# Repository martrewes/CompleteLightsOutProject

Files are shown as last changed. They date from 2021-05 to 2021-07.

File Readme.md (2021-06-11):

# Lights Out Physical project

- [Lights Out Physical project](#lights-out-physical-project)
  - [Intro](#intro)
  - [Edit 1](#edit-1)
    - [Items purchased so far:](#items-purchased-so-far)
    - [Dimensions of Items in mm](#dimensions-of-items-in-mm)
    - [Software](#software)
    - [Design](#design)
  - [Edit 2](#edit-2)
    - [PCB](#pcb)
  - [Edit 3](#edit-3)
  - [Edit 4](#edit-4)
    - [Button Layout](#button-layout)
    - [Serial Output](#serial-output)
  - [Edit 5](#edit-5)
    - [Playing with Sound](#playing-with-sound)
    - [**I made a grave mistake!!**](#i-made-a-grave-mistake)
  - [Edit 6](#edit-6)
    - [PCBs Arrived](#pcbs-arrived)
    - [It Verks!](#it-verks)
    - [More software work](#more-software-work)
  - [Edit 7](#edit-7)
    - [I haven't done much](#i-havent-done-much)
    - [Schematic/PCB Now Fixed](#schematicpcb-now-fixed)
- [Changes](#changes)

## Intro

After I had completed creating LightsOut in Python, I was going to make it again with a GUI. I started this process but it sort of fizzled out (though I am sure I will go back to it).

I decided in my _great wisdom_ to make a complete recreation of the game physically. The reasons for this are many, but overall I would like to achieve the following:

- Roughly design it
  - Have it use Batteries
  - Be able to charge it
  - Possibly have an additional display
  - Add sound?
- Create the circuit
- Create the PCB (and have it manufactured)
- Write the software (ESP32)
- Creating a housing (maybe send off for 3D printing)

It's quite a lofty ambition, maybe not if you're experienced which I certainly am not, but I do hope to achieve it.

## Edit 1

### Items purchased so far:

This table will be updated as and when

| Qty. | Item | Price | Arrived |
| ---- | --- | --- | --- |
| 60 | SK6812 5050 RGB LEDs | £5.00 | Yes |
| 30 | Gateron Switches Green (SMD Variant) | £9.45 | Yes |
| 1 | 15m Cat5e Cable (solid core) | £8.99 | No |
| 4 | Various pin connectors | £6.15 | No |
| 12 | 18650 Battery Holder | £6.99 | Yes |
| 5 | 1A/5V MicroUSB Li-Ion Battery Module | £6.99 | Yes |
| 1 | 60/40 Solder 100g | £6.37 | Yes |
| 1 | 1L Isopropanol 99.9% | £9.49 | Yes |
| 50 | 0.1uF 1206 SMD Capacitors | £2.30 | No |
| | **Total** | **£61.73** | |

### Dimensions of Items in mm

| Item Name | Length | Width | Height |
| --- | --- | ----- | --- |
| SK6812 5050 RGB LEDs | 5 | 5 | 1.6 |
| Gateron Switches Green (SMD Variant) | 15.8 | 15.6  | 18 |
| 18650 Battery Holder | 75.9 | 20.9  | 18.5 |
| 1A/5V MicroUSB Li-Ion Battery Module | 28.7 | 17.3  | 3.5 |
| PCB | TBD | TBD | 1.6 |
| Capacitors | 3.2 | 1.6 | 1 |

### Software

So I am starting to play around with the circuit idea. As I have never used addressable RGB led's before, I thought best to use an online simulator whilst I was waiting for them to arrive. (I will be using an ESP32 based board, however as I am just experimenting I am using an UNO online)
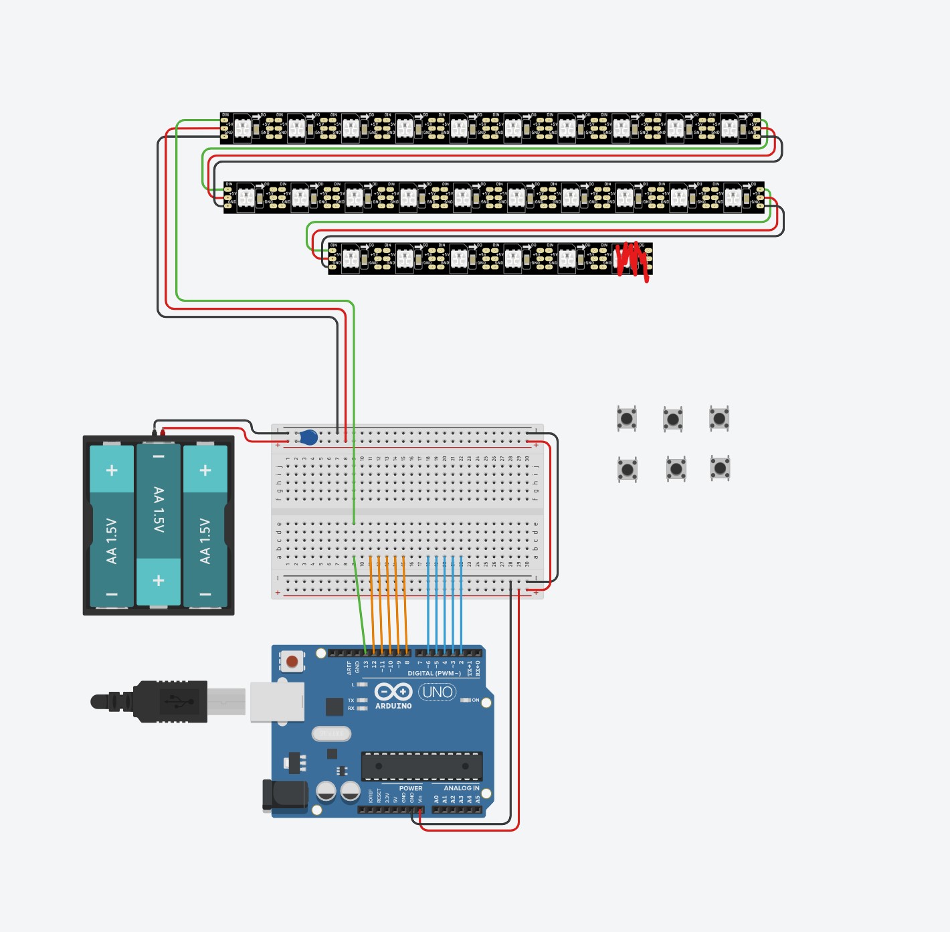
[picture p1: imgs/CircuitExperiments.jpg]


I have also done some rudimentary code along side this in the simulator to get a feel for how it works. So far I am just reading the colour of the LED, reporting it, and then changing it to another colour, rinse and repeat. I only plan to use green and red for this project.

```c++
#include <Adafruit_NeoPixel.h>

#define PIN		13
#define N_LEDS	25

Adafruit_NeoPixel strip = Adafruit_NeoPixel(N_LEDS, PIN, NEO_GRB + NEO_KHZ800);
//int req = 0;
//String hexer = "";
uint32_t red = strip.Color(255, 0, 0);
uint32_t green = strip.Color(0, 255, 0);
uint32_t active = green;
void setup()
{
  strip.begin();
  strip.show();
  Serial.begin(9600);
}

void loop()
{
  //(strip.Color(255, 0, 0)); // Red
  //(strip.Color(0, 255, 0)); // Green
  //(strip.Color(0, 0, 255)); // Blue
  strip.setPixelColor(2, active);
  strip.show();
  delay(1000);
  if (strip.getPixelColor(2) == green) {
    Serial.println("It's Green!");
    active = red;
  	strip.show();
  	}
  else {
    Serial.println("it's Red!");
    active = green;
  	strip.show();
	}

```

Next, in terms of software, I am going to work on the switch matrix and see how I can use them as a matrix.

### Design

I have also done a rough draft of what I think it will look like (completely not final). Obviously, there is a lot I need to change, but this was just to have an idea of where I am heading.
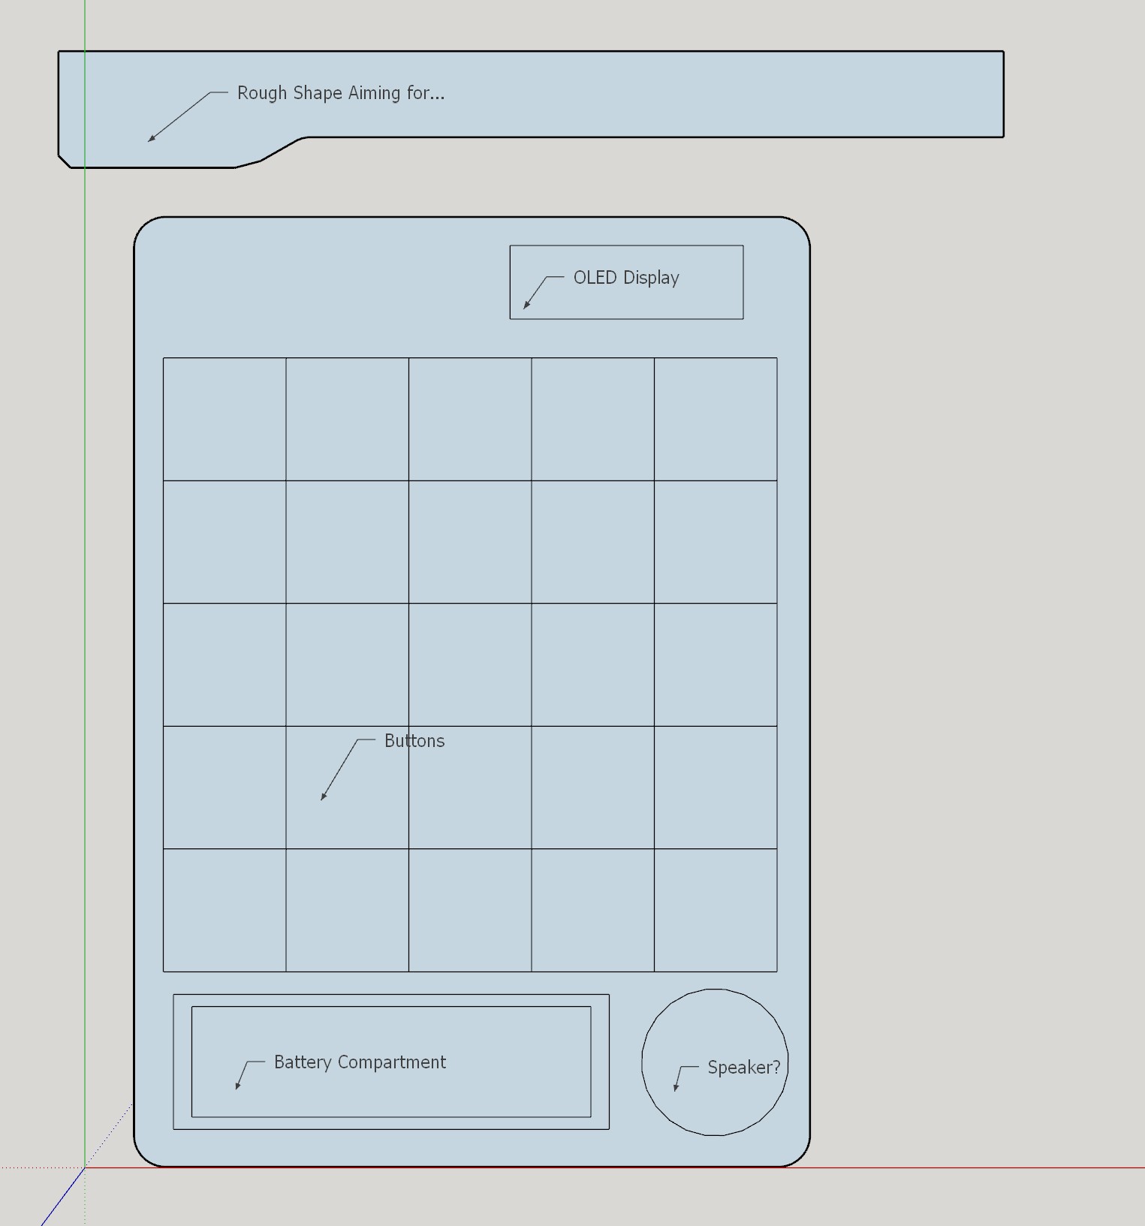
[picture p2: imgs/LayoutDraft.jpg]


## Edit 2

So I have been working on this a lot behind the scenes, but there has nothing of note really been done so far. Just a load of idea's on how to approach this. Thankfully some of the parts arrived today, so I have been able to measure and imagine how large the pcb needs to be etc. On top of that, I have also been working on a few PCB ideas.

### PCB

I think I have figured out the best way to approach it (Capacitors got in the way of progress there) and have two switches plotted and wired up below:
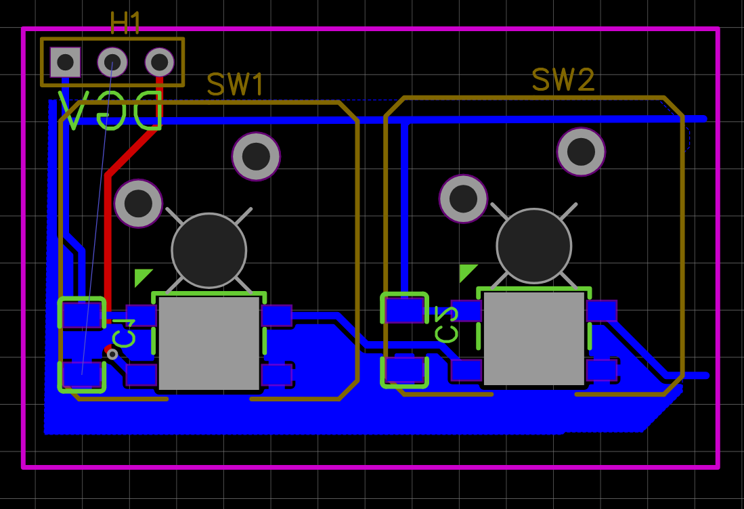
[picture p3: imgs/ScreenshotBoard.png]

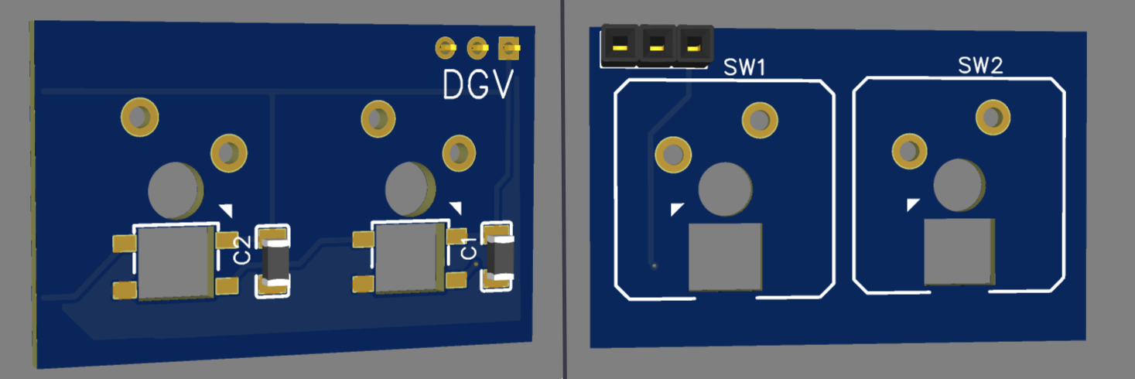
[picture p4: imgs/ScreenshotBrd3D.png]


The blue traces are on the underside of the board. I have managed to put all of the traces for the LEDs on this side, which will make routing the row and columns for the switches (red traces) much easier.

## Edit 3

So I have finally made the first PCB. It took far too long, but it isn't something I am a professional at. This is of the button pad (which was the hardest to design (I think)), and I know I probably made so many errors, but I completed it. I have sent it off for manufacture at just over £7, so I am not too worried if it doesn't work. At least I will have something physical and then I can progress from there. I think I will leave it here for today.
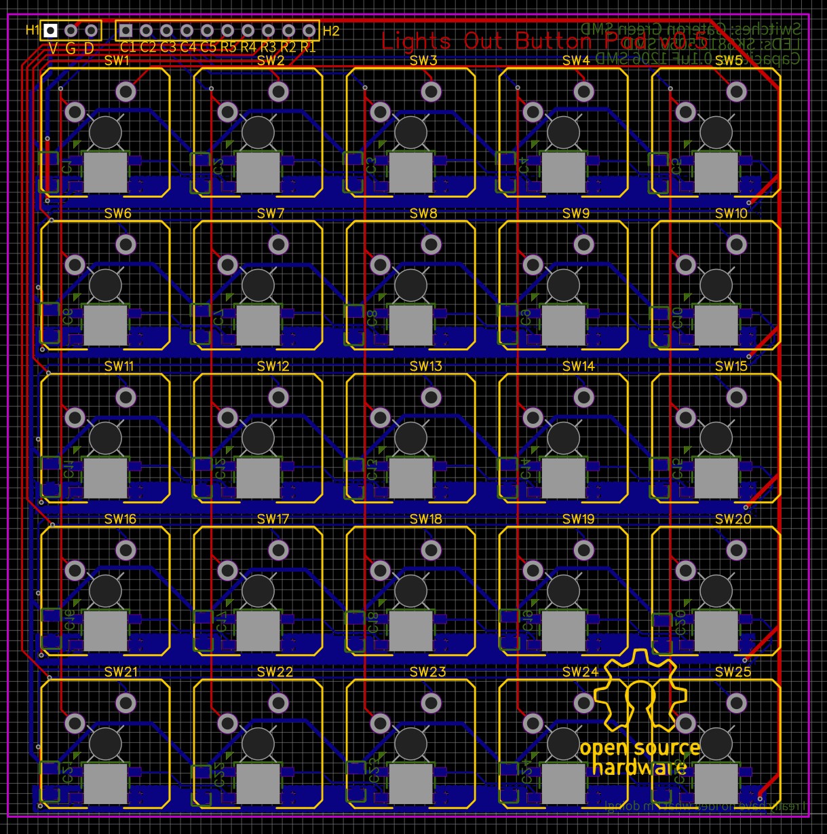
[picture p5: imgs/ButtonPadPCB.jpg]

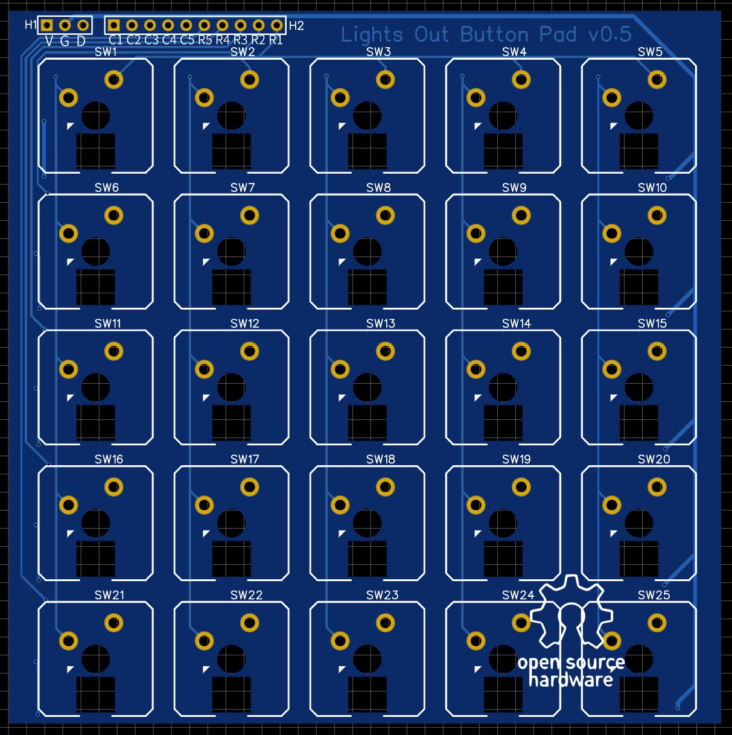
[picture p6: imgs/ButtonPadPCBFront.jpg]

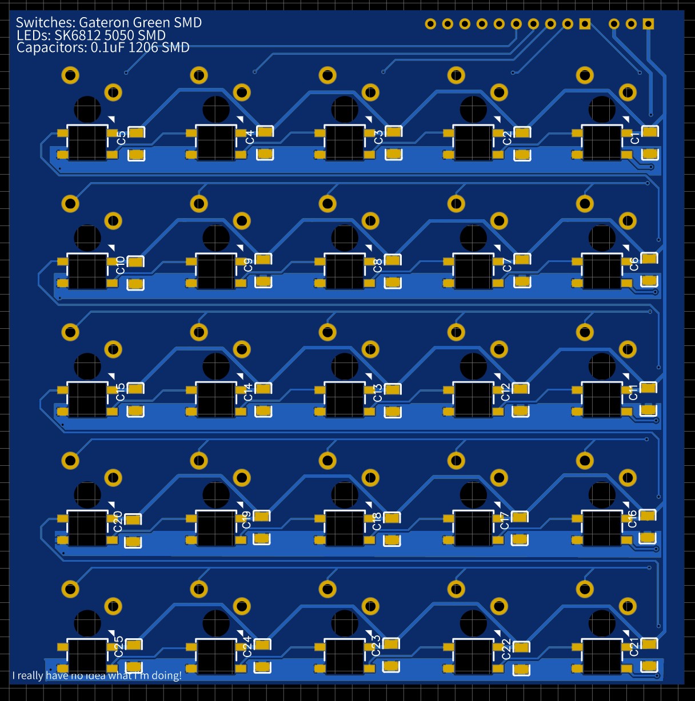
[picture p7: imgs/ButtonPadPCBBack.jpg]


## Edit 4

A lot of progress has been made today in terms of software. I have successfully managed to get it to the point of playing a level (displaying through the Serial Monitor), at the same time displaying what "button" has been pressed on a small screen. I am currently just joining assigned rows and columns together with a wire to simulate the button. So far the software can:

- Set up communications between it and the OLED display
- Read a level array and load it into its working array
- Calculate the sum of all "lights" that are on
- When that sum = 0, move out of the loop and on to the next level (need to populate those, yet)
- Display the "button" that was pressed on the small display
- Out put the board to the serial console (no light array yet)

I have decided to include the Arduino code into this repository now, so I don't forget to add it later. I'm really quite happy with how far I progressed today.

> Yes, I am fully aware that there is probably a much better way to handle the simple task I am trying to accomplish. I am not trying to copy anyone's ideas though, so I am just trying to make it work in what would make logical sense to me.

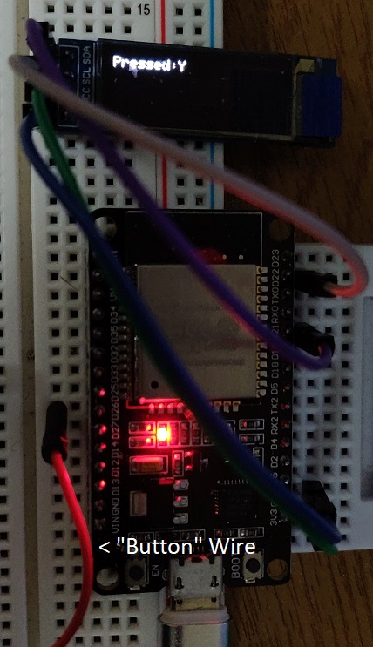
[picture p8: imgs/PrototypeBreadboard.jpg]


### Button Layout

| Col/Row | 1 | 2 | 3 | 4 | 5 |
| --- | --- | --- | --- | --- | --- |
| 1 | A | B | C | D | E |
| 2 | F | G | H | I | J |
| 3 | K | L | M | N | O |
| 4 | P | Q | R | S | T |
| 5 | U | V | W | X | Y |

### Serial Output

```bash
Level: 1
00000
00000
00000
10101
10101
U //'button' pressed
Going into routine
Level: 1
00000
00000
00000
00101
01101
Tot. On: 5
W
Going into routine
Level: 1
00000
00000
00000
00001
00011
Tot. On: 3
Y
Going into routine
Level: 1
00000
00000
00000
00000
00000
Tot. On: 1
Level Complete!!!

Level: 2
00000
00000
00000
10101
10101
```

## Edit 5

Seeing as I really now need to wait for my board to be manufactured until I can go any further, I decided to use this time to experiment a little.

### Playing with Sound

I managed to find an active speaker in with a bunch of random parts, so I decided to play around with the idea of adding sound. Turns out if all you want is a basic tone, it's quite easy with a built in Arduino function `tone()`. I have made some awful sounds with it, but my end goal is to have some sort of sound effect by playing several tones in quick succession. I will continue to play with this.

### **I made a grave mistake!!**

Never just blindly follow something you believe to be true.

Turns out, I wired the PCB completely wrong. I thought VSS was the positive polarity. In the back of my mind I did doubt this as I had seen VDD much more in the past, but I trudged on ahead as if I knew it all. I didn't!

Luckily, my PCB should be somewhat salvageable. I can cut the trace to the data in pin, then wire the LED the opposite way to the wires, and hook the data in from the bottom. This does mean I will also have to fix the sequence in code as I have been writing that assuming I was correct. I should just be able to reverse the data that I am sending through in theory, but it's still not ideal.

I will fix the PCB in the future, as well make it obvious where code will need to be omitted should it get wired up correctly in the future. Well, that was fun. Still, continue on I suppose.

## Edit 6

### PCBs Arrived

After much waiting ( which felt much more than last time, but was only 2 days longer), my PCBs finally arrived! I immediately started putting one together that afternoon, and...

### It Verks!

I was quite amazed. My soldering wasn't the best, but it worked out very well. The tolerances on the holes for the LEDs was perfect as it fit them very snug and was able to keep them in position whilst I soldered them in. All in all, I am very happy with the way it turned out. You will notice that I did have to cut the trace for the data line, so I could add a bodge wire to fix my [mistake](#i-made-a-grave-mistake) from the top, around the buttons and soldered to the data-in of LED 25.

*Back (Soldered)*  
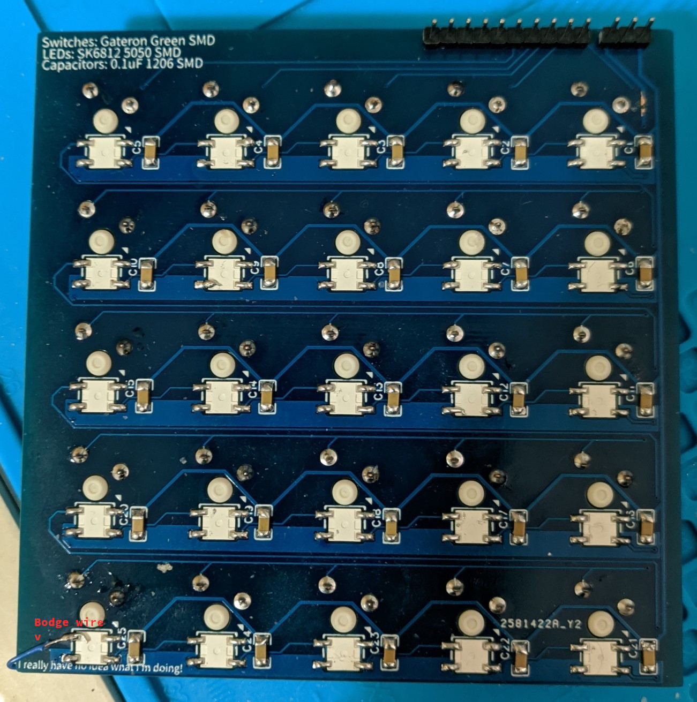
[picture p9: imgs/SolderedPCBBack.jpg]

*Front*    
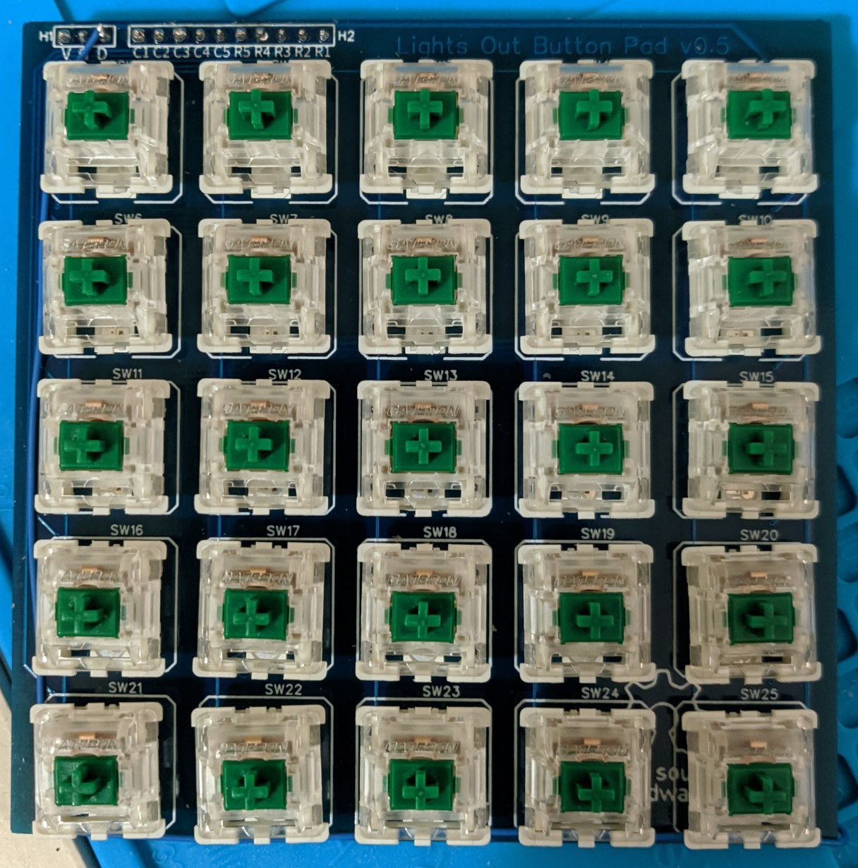
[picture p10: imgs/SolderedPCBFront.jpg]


### More software work

On Wednesday, I managed to [implement the code](https://github.com/martrewes/CompleteLightsOutProject/commit/c3f1d784189837028c2adabeba215a8f3a0d6ff0) to write data out to the LED string. This worked quite well, but I was too tired to continue once I had got it to work.

Today (Friday), I have worked solely on the software and have made quite the improvement. I have added 50 levels, implemented use of the screen to show what level you are on and how many moves you have made, and have done a massive clean-up of the code and added many comments (something I end up neglecting in the past). I'm quite excited to see how this goes going forward. There is still so much to do, though.  
*Close up of Display*  
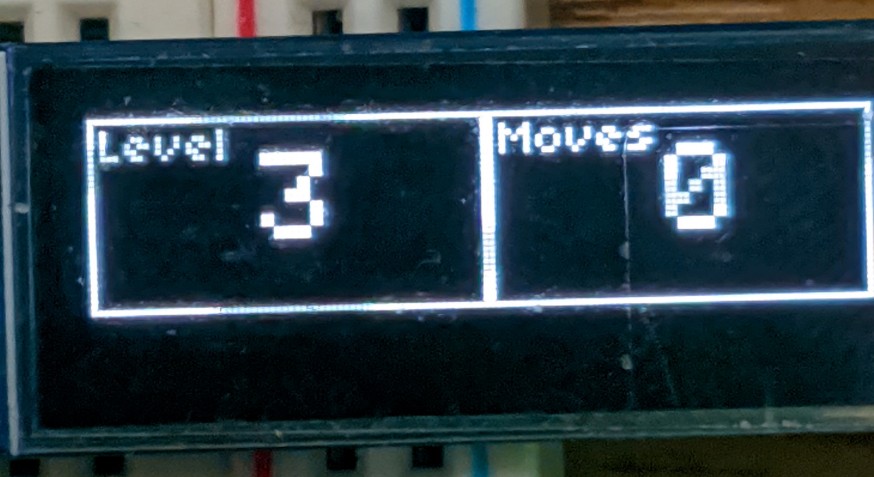
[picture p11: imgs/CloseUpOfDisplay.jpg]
  
*Demo*  


## Edit 7

### I haven't done much

I actually haven't done much with the project over the last week or so. Though I have been looking into how I can power the game. The original power modules I had purchased didn't output 5V like expected, just what ever the battery voltage was. I know I could make my own power circuit, I thought that would end up being far more work than it is worth. So I decided to buy a cheap power bank. I looked in the local Poundland and they didn't have any under £5, so I hunted around the town centre. I could not find anything until I got to CeX where I was able to purchase a pre-owned one for £0.75. So I have pulled this apart and will be using this to power the device.

### Schematic/PCB Now Fixed

I have just taken the time today to fix the schematic and PCB. The code to reverse the output to the LEDs will remain in my code until I can get the new PCB manufactured. I wasn't going to do this, but thought maybe it would be for the best as I can design the housing around the new one (which also has mounting holes), and if anyone wanted to build one it would be an easier process. So I think I am going to go ahead and do that.

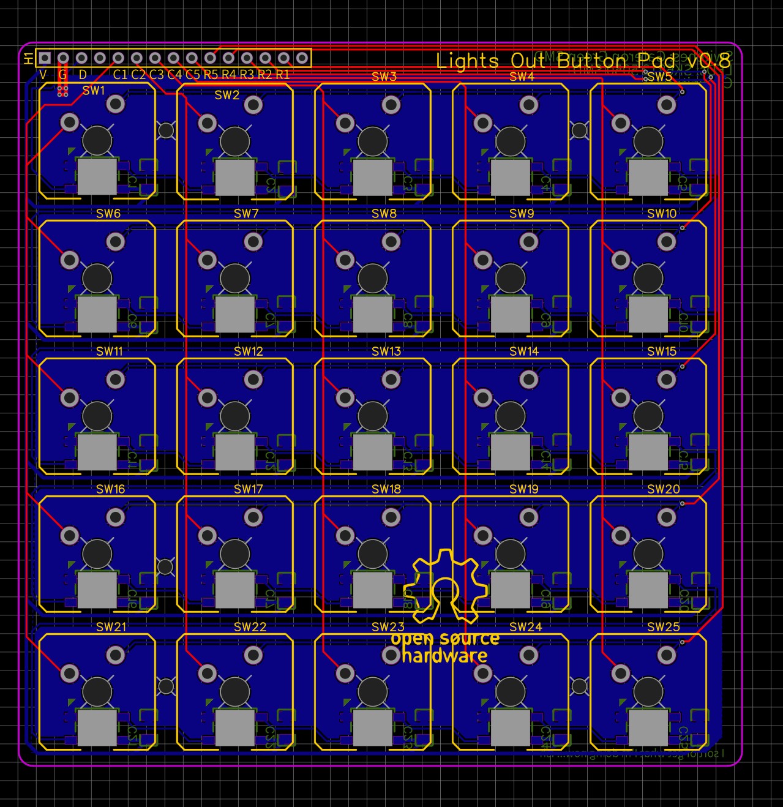
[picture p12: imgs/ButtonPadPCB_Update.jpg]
  
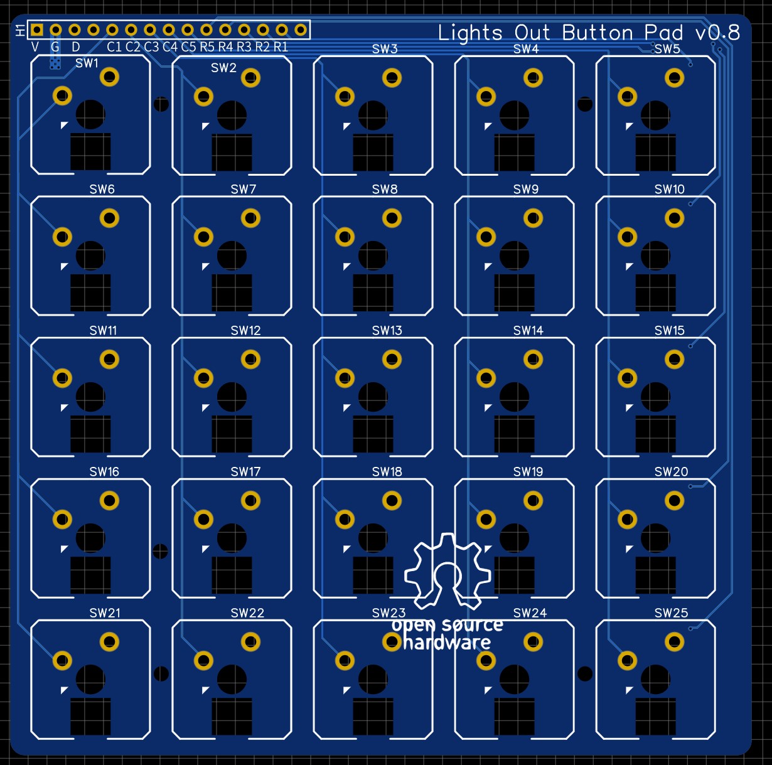
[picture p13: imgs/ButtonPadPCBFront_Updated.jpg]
  
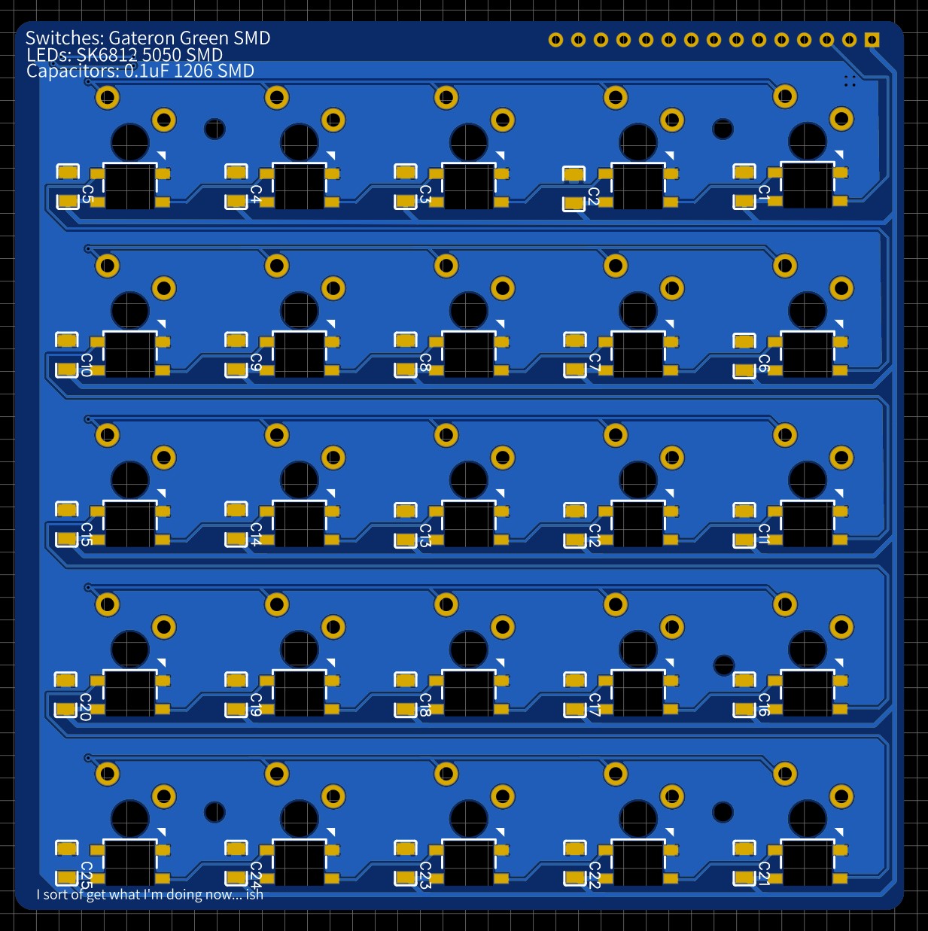
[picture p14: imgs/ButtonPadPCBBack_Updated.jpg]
  

Overall, I am still happy with how the progress is going with this, and looking forward to see what is next.

# Changes

- 31/04/2021
  - Initial Creation
  - Added price list
- 01/05/2021
  - Added Intro
  - Added battery holders, power boards and misc to price list
  - Added Dimensions table
  - Software notes
  - Design Notes
- 05/05/2021
  - Added PCB ideas
  - Items arrived
  - Added Capacitors to price list/dimensions
- 06/05/2021
  - Finally completed a PCB (1 of _n_) and sent off for manufacture
- 07/05/2021
  - Added software and made great progress!
- 10/05/2021
  - Added info about sound
  - Made an awful error which could have screwed the project
- 28/05/2021
  - Added info about PCB and software
- 11/06/2021
  - Added info about Power
  - Added new (fixed) PCB design

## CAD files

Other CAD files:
LayoutDraft.skp

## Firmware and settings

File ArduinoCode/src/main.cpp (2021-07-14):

#include <Arduino.h>
#include <Keypad.h>
#include <Wire.h>
#include <Adafruit_GFX.h>
#include <Adafruit_SSD1306.h>
#include <Adafruit_NeoPixel.h>
// levels.h contains all of the levels as well as the background image. I put them there to clean up variable declarations. It's already getting unweildy.
#include <levels.h>

// Definitions and initialisation for the screen
#define SCREEN_WIDTH 128 
#define SCREEN_HEIGHT 32 
#define OLED_RESET 4        
#define SCREEN_ADDRESS 0x3C ///< See datasheet for Address; 0x3D for 128x64, 0x3C for 128x32
Adafruit_SSD1306 display(SCREEN_WIDTH, SCREEN_HEIGHT, &Wire, OLED_RESET);

// Definitions and initialisation for the LED "strip"
#define PIN       15 
#define NUMPIXELS 25 
Adafruit_NeoPixel pixels(NUMPIXELS, PIN, NEO_GRB + NEO_KHZ800);

// Declaring variables required for the game
int levelSum = 1;             //used to tell if the level is complete
bool LevelComplete = false;   //used to pull out of the level loop
int LevelNo = 0;              //used to pull level data into currentLevel[]
int lvlMoves = 0;
bool twoColourMode = false;
int totLevels;

// Delare page number and if in Menu (on startup true)
int page = 1;
bool inMenu = true;

// Declarations and initialisation of the keypad (switch matrix)
const byte ROWS = 5;
const byte COLS = 5;
char Keys[ROWS][COLS] = {
    {'A', 'B', 'C', 'D', 'E'},
    {'F', 'G', 'H', 'I', 'J'},
    {'K', 'L', 'M', 'N', 'O'},
    {'P', 'Q', 'R', 'S', 'T'},
    {'U', 'V', 'W', 'X', 'Y'}};
byte rowPins[COLS] = {13, 12, 14, 27, 26}; //connect to the row pinouts of the keypad
byte colPins[ROWS] = {25, 33, 32, 4, 5};   //connect to the column pinouts of the keypad, 35 and 35 wouldn't work as input pins.
Keypad customKeypad = Keypad(makeKeymap(Keys), rowPins, colPins, ROWS, COLS);

// Define the variable that will contain the current level information on change
char currentLevel[25] = {'0', '0', '0', '0', '0', '0', '0', '0', '0', '0', '0', '0', '0', '0', '0', '0', '0', '0', '0', '0', '0', '0', '0', '0', '0'};
// Levels[] contains a list of all of the level information, included in levels.h
char * Levels[] = {Level1,Level2,Level3,Level4,Level5,Level6,Level7,Level8,Level9,Level10,
                   Level11,Level12,Level13,Level14,Level15,Level16,Level17,Level18,Level19,
                   Level20,Level21,Level22,Level23,Level24,Level25,Level26,Level27,Level28,
                   Level29,Level30,Level31,Level32,Level33,Level34,Level35,Level36,Level37,
                   Level38,Level39,Level40,Level41,Level42,Level43,Level44,Level45,Level46,
                   Level47,Level48,Level49,Level50};
char * LevelsHard[] = {HLevel1,HLevel2,HLevel3,HLevel4,HLevel5,HLevel6,HLevel7,HLevel8,HLevel9,
                      HLevel10,HLevel11,HLevel12,HLevel13,HLevel14,HLevel15,HLevel16,HLevel17,
                      HLevel18,HLevel19,HLevel20,HLevel21,HLevel22,HLevel23,HLevel24,HLevel25,
                      HLevel26,HLevel27,HLevel28,HLevel29,HLevel30,HLevel31,HLevel32,HLevel33,
                      HLevel34,HLevel35,HLevel36,HLevel37,HLevel38,HLevel39,HLevel40,HLevel41,
                      HLevel42,HLevel43,HLevel44,HLevel45,HLevel46,HLevel47,HLevel48,HLevel49,HLevel50};
char * LevelsXHard[] = {XHLevel1, XHLevel2, XHLevel3, XHLevel4, XHLevel5, XHLevel6, XHLevel7, XHLevel8, 
                        XHLevel9, XHLevel10, XHLevel11, XHLevel12, XHLevel13, XHLevel14, XHLevel15, 
                        XHLevel16, XHLevel17, XHLevel18, XHLevel19, XHLevel20, XHLevel21, XHLevel22, 
                        XHLevel23, XHLevel24, XHLevel25, XHLevel26, XHLevel27, XHLevel28, XHLevel29, 
                        XHLevel30, XHLevel31, XHLevel32, XHLevel33, XHLevel34, XHLevel35, XHLevel36, 
                        XHLevel37, XHLevel38, XHLevel39, XHLevel40, XHLevel41, XHLevel42, XHLevel43, 
                        XHLevel44, XHLevel45, XHLevel46, XHLevel47, XHLevel48, XHLevel49, XHLevel50};


//Declare subroutines
void ChangeData(int toChange[], int count);
void ChangeLights(char customKey);
void awaitKeyPress();
void checkLevel();
void PrintLevel();
void displayLEDs();
void updateDisplay();
void startGame();
void gameComplete();
void displayMenu();
void(* resetFunc) (void) = 0;

void setup()
{
  Serial.begin(9600); //Keeping on hand just in case, for now

  if (!display.begin(SSD1306_SWITCHCAPVCC, SCREEN_ADDRESS))
  {
    Serial.println(F("SSD1306 allocation failed"));
    for (;;)
      ; // Don't proceed, loop forever
  }
  //Starts LEDs
  pixels.begin();
  //Clear and display nothing on OLED (stops splash screen)
  display.clearDisplay();
  display.display();
  display.setTextSize(2);
  display.setTextColor(WHITE);
  //settle
  delay(500);
}

void loop()
{

displayMenu();
}

void awaitKeyPress()
{
  //Waits for a key to be pressed in the switch matrix
  char customKey = customKeypad.getKey();
  //If there is something..
  if (inMenu == true) {
      if (customKey == 'J' || customKey == 'D' || customKey == 'N') {
        if (page != 3) {
          page++;
          displayMenu();
        }
      }
      if (customKey == 'F' || customKey == 'B' || customKey == 'L') {
        if (page != 1) {
          page--;
          displayMenu();
        }
      }
      if (customKey == 'W' || customKey == 'V' || customKey == 'X') {
        if (page) {
          lvlMoves = 0;
          inMenu = false;
          startGame();
        }
      }
    
  }
  else if (customKey)
  {
    lvlMoves++;                 // Add 1 to moves counter
    ChangeLights(customKey);    // Modify current level array using the pressed key
    displayLEDs();              // Reflect the change on the LEDs
    updateDisplay();            // Update the OLED to show move counter increased
  }
}

void ChangeLights(char customKey)
{
  // The keys are laid out in a 5x5 matrix, and I wanted to ensure I had a few spare characters in case I wanted to add 
  // more control buttons in the future
  // I did try to clean this up a bit, by moving out the change data routine from each if statement, but unfortunately
  // you can not change an array size once it has been declared by the seems of things.

  if (customKey == 'A')
  {
    // Creates an array to pass to the change data routine
    int toChange[] = {0, 1, 5};                                   // These are the locations that will be manipulated in the matrix
    ChangeData(toChange, sizeof(toChange) / sizeof(toChange[0])); // Run the change data routine, which passes in the array and size
  }
  if (customKey == 'B')
  {
    int toChange[] = {0, 1, 2, 6};
    ChangeData(toChange, sizeof(toChange) / sizeof(toChange[0]));
  }
  if (customKey == 'C')
  {
    int toChange[] = {1, 2, 3, 7};
    ChangeData(toChange, sizeof(toChange) / sizeof(toChange[0]));
  }
  if (customKey == 'D')
  {
    int toChange[] = {2, 3, 4, 8};
    ChangeData(toChange, sizeof(toChange) / sizeof(toChange[0]));
  }
  if (customKey == 'E')
  {
    int toChange[] = {3, 4, 9};
    ChangeData(toChange, sizeof(toChange) / sizeof(toChange[0]));
  }
  if (customKey == 'F')
  {
    int toChange[] = {0, 5, 6, 10};
    ChangeData(toChange, sizeof(toChange) / sizeof(toChange[0]));
  }
  if (customKey == 'G')
  {
    int toChange[] = {1, 5, 6, 7, 11};
    ChangeData(toChange, sizeof(toChange) / sizeof(toChange[0]));
  }
  if (customKey == 'H')
  {
    int toChange[] = {2, 6, 7, 8, 12};
    ChangeData(toChange, sizeof(toChange) / sizeof(toChange[0]));
  }
  if (customKey == 'I')
  {
    int toChange[] = {3, 7, 8, 9, 13};
    ChangeData(toChange, sizeof(toChange) / sizeof(toChange[0]));
  }
  if (customKey == 'J')
  {
    int toChange[] = {4, 8, 9, 14};
    ChangeData(toChange, sizeof(toChange) / sizeof(toChange[0]));
  }
  if (customKey == 'K')
  {
    int toChange[] = {5, 10, 11, 15};
    ChangeData(toChange, sizeof(toChange) / sizeof(toChange[0]));
  }
  if (customKey == 'L')
  {
    int toChange[] = {6, 10, 11, 12, 16};
    ChangeData(toChange, sizeof(toChange) / sizeof(toChange[0]));
  }
  if (customKey == 'M')
  {
    int toChange[] = {7, 11, 12, 13, 17};
    ChangeData(toChange, sizeof(toChange) / sizeof(toChange[0]));
  }
  if (customKey == 'N')
  {
    int toChange[] = {8, 12, 13, 14, 18};
    ChangeData(toChange, sizeof(toChange) / sizeof(toChange[0]));
  }
  if (customKey == 'O')
  {
    int toChange[] = {9, 13, 14, 19};
    ChangeData(toChange, sizeof(toChange) / sizeof(toChange[0]));
  }
  if (customKey == 'P')
  {
    int toChange[] = {10, 15, 16, 20};
    ChangeData(toChange, sizeof(toChange) / sizeof(toChange[0]));
  }
  if (customKey == 'Q')
  {
    int toChange[] = {11, 15, 16, 17, 21};
    ChangeData(toChange, sizeof(toChange) / sizeof(toChange[0]));
  }
  if (customKey == 'R')
  {
    int toChange[] = {12, 16, 17, 18, 22};
    ChangeData(toChange, sizeof(toChange) / sizeof(toChange[0]));
  }
  if (customKey == 'S')
  {
    int toChange[] = {13, 17, 18, 19, 23};
    ChangeData(toChange, sizeof(toChange) / sizeof(toChange[0]));
  }
  if (customKey == 'T')
  {
    int toChange[] = {14, 18, 19, 24};
    ChangeData(toChange, sizeof(toChange) / sizeof(toChange[0]));
  }
  if (customKey == 'U')
  {
    int toChange[] = {15, 20, 21};
    ChangeData(toChange, sizeof(toChange) / sizeof(toChange[0]));
  }
  if (customKey == 'V')
  {
    int toChange[] = {16, 20, 21, 22};
    ChangeData(toChange, sizeof(toChange) / sizeof(toChange[0]));
  }
  if (customKey == 'W')
  {
    int toChange[] = {17, 21, 22, 23};
    ChangeData(toChange, sizeof(toChange) / sizeof(toChange[0]));
  }
  if (customKey == 'X')
  {
    int toChange[] = {18, 22, 23, 24};
    ChangeData(toChange, sizeof(toChange) / sizeof(toChange[0]));
  }
  if (customKey == 'Y')
  {
    int toChange[] = {19, 23, 24};
    ChangeData(toChange, sizeof(toChange) / sizeof(toChange[0]));
  }
}

void ChangeData(int toChange[], int count)
{
  // Temporarily set the level sum to 0, so it can be recounted
  levelSum = 0;
  // Start a for loop to only change relevent data in the array
  if (twoColourMode == true) {
    for (int No = 0; No < count; No++)
    {
    // If the character in the array at the position supplied is equal to 0, change it to 1, else if it's 1, change it to zero.
    // As of 30/06/21 I added one additional state for red. Looping from 2, 1 to 0.
    // I deliberately used an else if, so I could possibly add more characters (more colours) in the future 
      if (currentLevel[toChange[No]] == '0')
      {
        currentLevel[toChange[No]] = '2';
      }
      else if (currentLevel[toChange[No]] == '2')
      {
        currentLevel[toChange[No]] = '1';
      }
      else if (currentLevel[toChange[No]] == '1')
      {
        currentLevel[toChange[No]] = '0';
      }
    }
  }
  else {
    for (int No = 0; No < count; No++)
    {
      if (currentLevel[toChange[No]] == '0')
      {
        currentLevel[toChange[No]] = '1';
      }
      else if (currentLevel[toChange[No]] == '1')
      {
        currentLevel[toChange[No]] = '0';
      }
    }
  }
  // Start the counting routine to see if any lights are still on
  for (int i = 0; i < 24; i++)
  {
    if (currentLevel[i] != '0')   // This may be changed to "!= '0' " to account for different characters in the future
    {
      levelSum = levelSum + 1;
    }
  //  else
  //  {
  //    levelSum = levelSum; //Don't really think I need this statement, commented out.
  //  }
  }
}

void PrintLevel()
{
  // This routine just printed out the level map to the serial port. Was useful before the PCBs showed up.
  // I will keep this routine in for the time being in the case that I need it (eg. Developing without the hardware)
  for (byte i = 0; i < 5; i++)
  {
    Serial.print(currentLevel[i]);
  }
  Serial.println();
  for (byte i = 5; i < 10; i++)
  {
    Serial.print(currentLevel[i]);
  }
  Serial.println();
  for (byte i = 10; i < 15; i++)
  {
    Serial.print(currentLevel[i]);
  }
  Serial.println();
  for (byte i = 15; i < 20; i++)
  {
    Serial.print(currentLevel[i]);
  }
  Serial.println();
  for (byte i = 20; i < 25; i++)
  {
    Serial.print(currentLevel[i]);
  }
  Serial.println();
}

void displayLEDs()
{
  int adj = 24;     // Okay so this was my fix to the mistake I made to the PCB. Ideally I wouldn't need this, but I wasn't just going to order another lot of PCBs
                    // as I was able to change it in code. This will be commented out once I have fixed the PCB design.
  pixels.clear();   // Clear the data for the LEDs so it can be rebuilt.
  for (int i = 0; i <= 24; i++)
  {
    if (currentLevel[i] == '2'){
      // If the current (adjusted) location contains a 2, light up that LED Red
      pixels.setPixelColor(adj, pixels.Color(50, 0, 0));
    }
    else if (currentLevel[i] == '1') {
      // // If the current (adjusted) location contains a 1, light up that LED Green
      pixels.setPixelColor(adj, pixels.Color(0, 50, 0));
    }
    else if (currentLevel[i] == '0') {
      // If it's a 0, do not light it.
      pixels.setPixelColor(adj, pixels.Color(0, 0, 0));
    }
    adj--;          // Remove 1 from the adjustment so it can continue working backwards
  }
  pixels.show();    // Show the changes to the LEDs
}

void updateDisplay() {
  // A catch-all routine to change the data on the OLED display
  display.clearDisplay();                         // Clear the buffer.
  display.drawBitmap(0,0,bgImage,128,32,WHITE);   // Draw the background.
  display.setCursor(28, 10);                      // Set the cursor and display the Level No
  display.print(String(LevelNo + 1));             // as it starts at zero, add 1.
  if (lvlMoves > 99){
    display.setCursor(88,10);
  }
  else{
  display.setCursor(98, 10);
  }                      // Move the cursor to the second location
  display.print(String(lvlMoves));                // to display the amount of moves.
  display.display();                              // Write to the display.
}

void startGame(){
    // Nested loops make up the level logic. 
    while (LevelNo < 50)
  {
  //Initialise the Level -----
    //Level complete needs to be set as false, this will allow me to pull out of the current level loop
    LevelComplete = false;
    // Copy level data into currentLevel array, dependant on difficulty
    if (page == 1) {
      memcpy(currentLevel, Levels[LevelNo], sizeof(currentLevel));
    }
    else if (page == 2) {
      memcpy(currentLevel, LevelsHard[LevelNo], sizeof(currentLevel));
    }
    else if (page == 3) {
      memcpy(currentLevel, LevelsXHard[LevelNo], sizeof(currentLevel));
    }
    
    
    // Show the level on the LEDs
    displayLEDs();
    //Update the display to reflect level change
    updateDisplay();

    //This is the first verification to tell if the level has been complete
    while (LevelComplete == false)
    {
      //Second verification, so I can come out of this if statement, flip the levelComplete bool, then initialise the next level.
      if (levelSum > 0)
      {
        awaitKeyPress();
      }
      else
      {
        //Flip the bool
        LevelComplete = true;
        //Add 1 to LevelNo, and reset number of moves and level sum.
        LevelNo++;
        lvlMoves = 0;
        levelSum = 1;
      }
    }
  }
  gameComplete();
}

void gameComplete() {
  display.clearDisplay();
  display.setCursor(10,18);
  display.print("Game Comp.");
  display.display();
  delay(3000);
  resetFunc();
}

void displayMenu() {
  memcpy(currentLevel, menuLeds, sizeof(currentLevel));
  displayLEDs();
  display.clearDisplay();
  display.drawBitmap(0,0,menu_bgMenubg,128,32,WHITE);
  
  //while (page > 0) {
    if (page == 1) {
      //display.clearDisplay();
      display.setCursor(4,12);
      display.print("   Easy  >");
      display.display();
      twoColourMode = false;
      totLevels = 50;
    }
    if (page == 2) {
      //display.clearDisplay();
      display.setCursor(4,12);
      display.print("<  Hard  >");
      display.display();
      twoColourMode = true;
      totLevels = 25;
    }
    if (page == 3) {
      //display.clearDisplay();
      display.setCursor(4,12);
      display.print("<  XHard  ");
      display.display();
      twoColourMode = true;
      totLevels = 50;
    }
  awaitKeyPress();
  //}

}
//  Current Stats.
//  RAM:   [=         ]   5.2% (used 17056 bytes from 327680 bytes)
//  Flash: [==        ]  19.5% (used 255018 bytes from 1310720 bytes)

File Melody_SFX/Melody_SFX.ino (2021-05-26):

/*
  Melody

  Plays a melody

  circuit:
  - 8 ohm speaker on digital pin 8

  created 21 Jan 2010
  modified 30 Aug 2011
  by Tom Igoe

  This example code is in the public domain.

  https://www.arduino.cc/en/Tutorial/BuiltInExamples/toneMelody
*/

#include "pitches.h"

// notes in the melody:
int melody[] = {
  NOTE_C4, NOTE_G3, NOTE_G3, NOTE_A3, NOTE_G3, 0, NOTE_B3, NOTE_C4
};

// note durations: 4 = quarter note, 8 = eighth note, etc.:
int noteDurations[] = {
  4, 8, 8, 4, 4, 4, 4, 4
};

void playMelody(int dur){
    for (int thisNote = 0; thisNote < 8; thisNote++) {

    // to calculate the note duration, take one second divided by the note type.
    //e.g. quarter note = 1000 / 4, eighth note = 1000/8, etc.
    int noteDuration = dur / noteDurations[thisNote];
    tone(11, melody[thisNote], noteDuration);

    // to distinguish the notes, set a minimum time between them.
    // the note's duration + 30% seems to work well:
    int pauseBetweenNotes = noteDuration * 2;
    delay(pauseBetweenNotes);
    // stop the tone playing:
    noTone(11);
}
}


void setup() {
  // iterate over the notes of the melody:

  
}

void loop() {
    playMelody(500);
    delay(1000);
    playMelody(50);
    delay(1000);
}

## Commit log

2021-05-07 Added arduino code, updated readme
2021-05-07 Fixed button table
2021-05-26 Added lights and sound (PCB Arrived)
2021-05-28 fixed spellings in comments
    [main.cpp]
2021-06-11 Updated readme for new pcb etc
2021-06-30 Added framework for more than one colour of LED
2021-07-08 Finally added a Menu! Have also made it only one game routine The move number doesn't go off the screen
    [main.cpp]
